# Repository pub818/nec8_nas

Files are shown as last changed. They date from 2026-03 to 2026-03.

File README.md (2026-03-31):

# NEC8_NAS: 12-Bay High-Performance DIY NAS

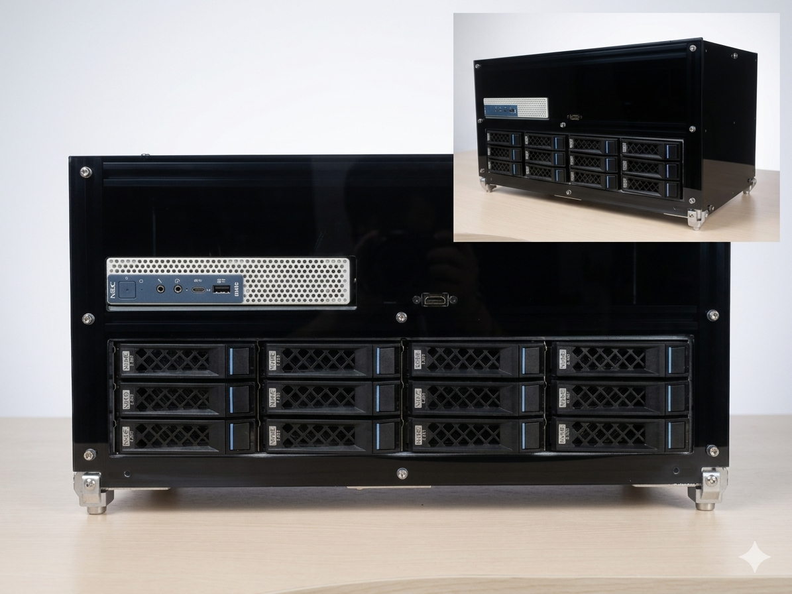
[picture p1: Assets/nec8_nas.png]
NEC8_NAS 成品图


基于 NEC8 微型主机的 12 盘位高性能 DIY NAS 方案。本项目通过硬件转接与铝型材结构重塑，构建了一个兼顾计算性能与海量存储的家庭实验室中心。

## 核心特性
* **企业级存储能力**：集成 **LSI 9300-8e** HBA 阵列卡，通过外部 Mini-SAS 线缆驱动 **12 盘位勤诚（Chenbro）硬盘笼**。
* **网络带宽升级**：利用 M.2 A-E Key (原 WiFi 接口) 转接 **2.5G 有线网卡 (RTL8125B)**。
* **极限散热优化**：利用转接卡板载 **XH2.54 12V 接口** 为 LSI 阵列卡加装主动散热风扇，解决 9300 系列高温掉盘痛点。
* **全模组供电方案**：采用 **爱国者 (aigo) ES650 金牌全模组电源**，为 12 块硬盘提供稳定的启动电流。
* **自动化同步启动**：集成 **USB 电源同步启动模块**，实现 NAS 主机与硬盘笼电源一键同步开关。
* **自研框架结构**：采用 2020 欧标铝型材 + 自设计亚克力机箱，兼顾稳固与散热风道。

## 硬件清单 (BOM)
| 组件 | 型号/规格 | 备注 |
| :--- | :--- | :--- |
| **主机** | NEC8 (微型主机) | 核心计算单元 |
| **硬盘笼** | 勤诚 (Chenbro) 12 盘位 | 企业级热插拔背板 |
| **HBA卡** | LSI 9300-8e (IT Mode) | 驱动 12 盘位存储 |
| **电源** | 爱国者 ES650 金牌全模组 | 标准 ATX 规格 |
| **启动模块** | USB 电源同步模块 | 解决双电源同步开关问题 |
| **网卡** | M.2 A-E Key 转 2.5GbE | 内网带宽升级 |
| **框架** | 2020/2040 欧标铝型材 | 自研 CAD 结构设计 |

## 设计文件与脚本
本项目包含用于生成机箱板材的脚本与图纸：
* `/Scripts`: 包含自动化生成 DXF 设计文件的 Python 脚本。
    * 支持**无倒角（No Chamfer）**版本，适配自装机箱脚垫。
    * 已优化孔位，移除与电源开口冲突的冗余螺丝孔。
* `/CAD`: 存放最终版 DXF 激光切割/CNC 加工图纸。

## 版权与致谢 (Credits)
* **设计与维护**: [pub818 (帕步科技)](https://pub818.com)
* **创作理念**: **Designed by Human · Assisted by AI**
* **许可协议**: 本项目遵循 [MIT License](./LICENSE) 开源。

---
*更多详细的装机心路历程与软件配置，请参考我的个人博客：[pub818.com](https://pub818.com)*

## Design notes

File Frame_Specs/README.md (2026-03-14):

# NEC8_NAS 框架规格书 (Frame Specifications)

本项目 NAS 采用自研铝型材框架结构。本目录提供用于复刻该框架的精确下料清单 (BOM) 和组装技术要求。

## 框架结构插图 (BOM Visual)

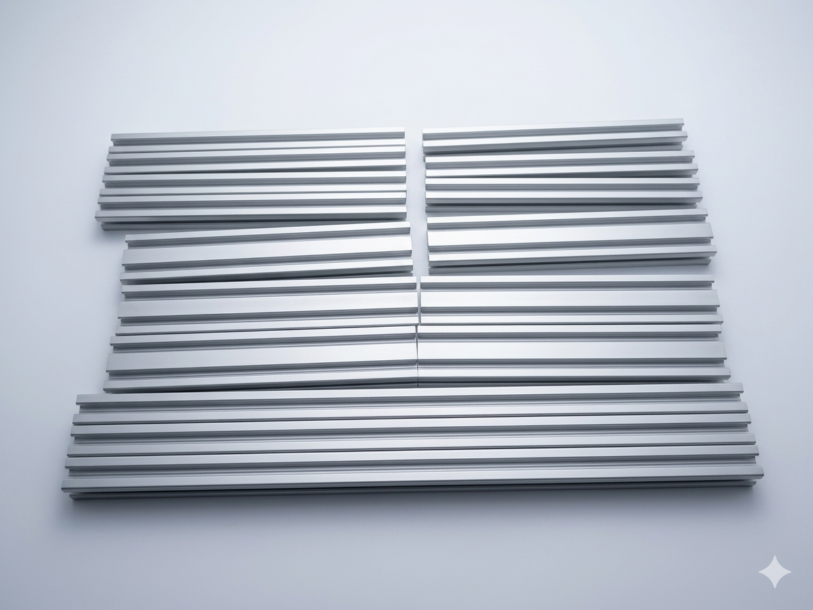
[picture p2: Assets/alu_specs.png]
处理后的铝挤压材清单

*注：图中展示为项目实际切割完成后的型材，带有保护膜，采用中性背景净化处理以突出规格。*

## 铝型材下料清单 (Alu Extrusion BOM)

本项目使用 **2020 欧标 (European Standard)** 和 **2040 欧标** 银色阳极氧化铝型材。

### 1. 2020 规格 (20mm x 20mm)

| 型号 | 长度 (Length) | 数量 (Quantity) | 备注 (Note) |
| :--- | :--- | :--- | :--- |
| **2020** | **440 mm** | **6 根** | 框架纵向长梁 |
| **2020** | **244 mm** | **4 根** | 框架立柱 |
| **2020** | **220 mm** | **3 根** | 硬盘笼/电源横向支撑 |

### 2. 2040 规格 (20mm x 40mm)

| 型号 | 长度 (Length) | 数量 (Quantity) | 备注 (Note) |
| :--- | :--- | :--- | :--- |
| **2040** | **220 mm** | **6 根** | 框架底部/顶部主承重横梁 |

## 连接件与紧固件 (Connectors & Fasteners)

为了追求整体外观的简洁和稳固性，本项目全部采用**内置式角槽连接**。

* **内置角槽连接件** (Inner Corner Connectors)：**共 48 个**。
* **配套紧固螺丝**：配套 48 套（通常随角槽连接件一起出售）。

## 技术要求 (Technical Requirements)

1. **切割精度**：铝型材切割长度公差建议控制在 **±0.5mm** 以内，确保框架组装时的直角度。
2. **切面要求**：切割面必须保证垂直度（Squareness），切忌倾斜，否则会严重影响整体框架的稳定性。

---
[<- 返回项目主页](../README.md) | **Designed by [pub818](https://pub818.com)**

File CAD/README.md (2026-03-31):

## 📐 CAD 设计文件说明 (CAD Design Files)

本项目包含用于亚克力面板切割的 DXF 原始设计稿及优化迭代版本。

### 1. 核心切割文件

#### 🔹 原始验证版：`Full_Case_Design_Final.dxf`
* **状态：** 已验证。
* **说明：** 本项目首个实物成品即采用此文件进行亚克力板材切割。
* **注意：** 侧板螺丝孔位为 3.0mm 标准孔，对加工精度要求极高，组装时容错率较低。

#### 🔹 推荐迭代版：`HardDrive_Case_V5_3.5mm_Holes.dxf`
* **状态：** 推荐使用。
* **优化：** * **孔径扩增**：将侧板螺丝孔径统一修正为 **3.5mm**，为手动组装预留了必要的物理旷量（Tolerance），有效解决了因公差导致的安装困难。
    * **布局修正**：微调了顶板开孔坐标，解决了原版开孔位置略微偏上的问题，视觉对齐更趋完美。

---

### 🖼️ 设计示意图 (Design Preview)

以下是散热模块及硬盘笼侧板的 CAD 布局参考：

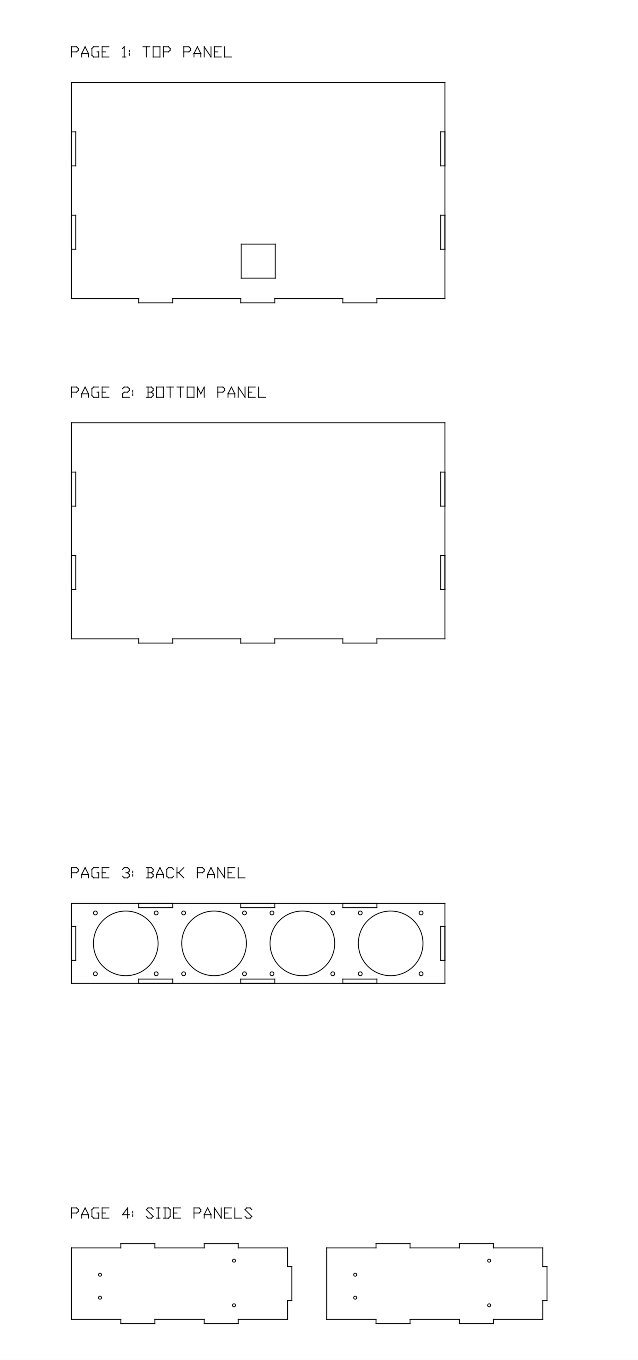
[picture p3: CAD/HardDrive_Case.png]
散热模块设计预览

*注：加工前请根据实际使用的亚克力板材厚度，在 CAD 软件中复核榫卯及开孔尺寸。*

---

### 🏗️ 框架结构参考

#### ⚠️ 参考文件：`Server_Rack_Final_Separated.dxf`
* **用途：** 此文件仅作为**铝型材机箱框架的安装逻辑示意图**。
* **警告：** 请勿直接使用此 DXF 文件进行铝型材的切割或下单，框架的具体规格请以项目提供的 [BOM 清单](#)（如有）或实际测量数据为准。

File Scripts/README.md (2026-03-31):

## 📂 文件说明与版本迭代

本项目包含两个核心脚本，用于生成勤诚硬盘笼散热模块的 CAD 设计文件。

### 1. case_all_v2.py (原始版本)
> **状态：** 已验证。本项目第一个成品即采用此文件生成。

这是最原始的散热模块生成脚本，虽然能够成功加工，但在实际装配中发现了以下细节问题：

* **螺丝孔位精度要求极高**：侧板固定孔设计为 **3.0mm 标准孔**，未预留任何旷量。如果加工精度（如激光切割或 3D 打印）稍有偏差，安装时容错率较低，可能导致螺丝难以锁入。
* **外观细节**：顶板预留的方孔位置略微偏上。虽然不影响结构强度和实际使用，但在视觉观感上不够对称。

---

### 2. create_hard_drive_case.py (优化版本)
> **状态：** 推荐版本。针对装配体验进行了针对性改良。

基于 `case_all_v2.py` 的反馈，此版本进行了以下关键更新：

* **提升安装容错率**：将两块侧板的固定螺丝孔径从 3.0mm 扩大至 **3.5mm**。这为手动组装留出了必要的物理余量，能有效抵消加工公差带来的影响。
* **优化视觉对齐**：修正了顶板开孔的位置参数，使其视觉上更加居中协调。

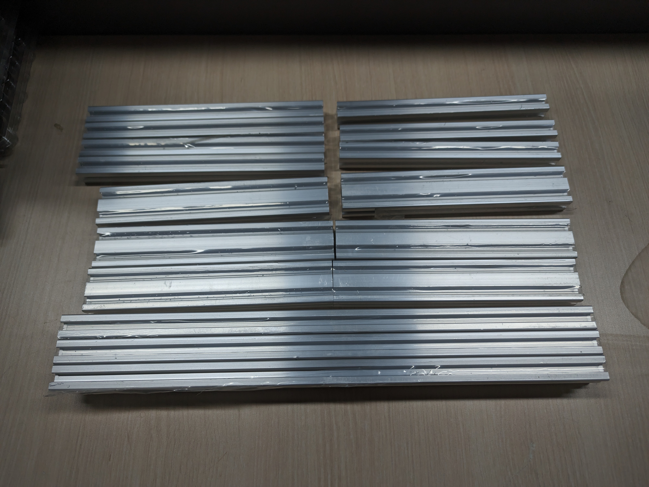
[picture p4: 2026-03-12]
Assets/alu_specs.jpg

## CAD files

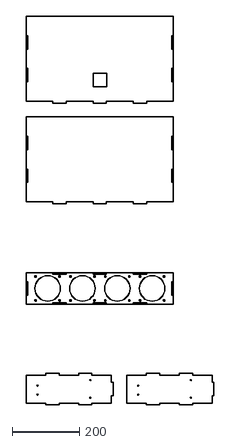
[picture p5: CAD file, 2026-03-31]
CAD/Full_Case_Design_Final.dxf
559.0 x 1159.0

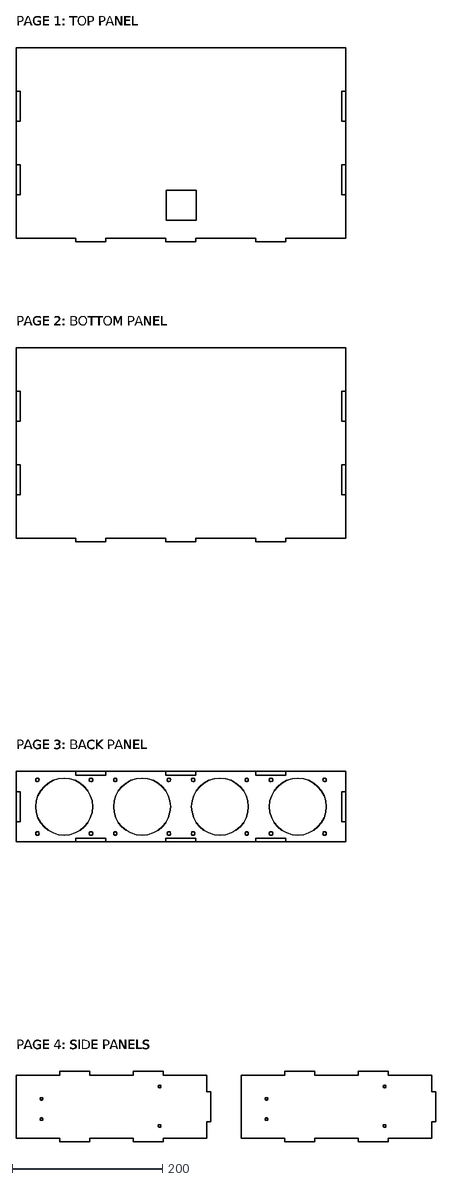
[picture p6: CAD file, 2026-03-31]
CAD/HardDrive_Case_V5_3.5mm_Holes.dxf
PAGE 1: TOP PANEL
PAGE 2: BOTTOM PANEL
PAGE 3: BACK PANEL
PAGE 4: SIDE PANELS

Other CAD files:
CAD/Server_Rack_Final_Separated.dxf

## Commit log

2026-03-14 Update README.md
    更新题图
2026-03-31 Add files via upload
    增加脚本及CAD文件
    [Full_Case_Design_Final.dxf, HardDrive_Case_V5_3.5mm_Holes.dxf, Server_Rack_Final_Separated.dxf]
2026-03-31 Create README.md
    增加说明文件
2026-03-31 Add files via upload
    增加成品图
2026-03-31 Create README.md
    添加各个CAD文件的说明。
2026-03-31 Update README.md
    修改框架细节，说明是2020及2040混合构成。
